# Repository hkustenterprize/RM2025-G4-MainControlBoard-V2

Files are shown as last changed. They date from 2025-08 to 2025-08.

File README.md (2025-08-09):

<div align='center'>
    <h1>RM2025 G4主控板V2</h1>
</div>

<div align='center'>
    <h2>RM2024香港科技大学ENTERPRIZE</h2>
</div>



**开源论坛链接：**

**欢迎加入开源交流QQ群：581184202**

## 文件内容

核心板：[点击在线预览](https://kicanvas.org/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)

扩展板：[点击在线预览](https://kicanvas.org/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)

~~~
RM2025-G4-MainControlBoard-V2
├── image
├── RM2025_G473_MCB             > 核心板工程文件
├── RM2024_G473_MCB_StdExtend   > 标准扩展板工程文件
├── LICENSE
└── README.md
~~~

开源工程文件设计软件为 **KiCAD 8.0**，可以导入立创EDA

每个工程文件文件夹中的内容:

~~~
xxx
├── ibom             > 焊接工具，由 "Interactive HTML BOM" 插件生成
├── production      > 生产文件，由 "Fabrication Toolkit" 插件生成，将其中的zip文件拖入JLC下单助手即可
├── xxx.kicad_pcb   > PCB
├── xxx.kicad_pro   > 主工程，通过双击这个启动KiCAD
└── xxx.kicad_sch   > 原理图
~~~

## 重要参数

主控板分为核心板（下板）和扩展板（上板），两板之间使用80pin BTB接口连接，尺寸上保持为与C板一致的 60x40mm；核心板包含所有核心芯片，扩展板用于引出接口或进行其他功能的扩展。

- MCU: STM32G473VET6
- IMU: ICM-42688P
- TTL: CH343P *2 
- FDCAN *3
- RS485 (硬件流控) *1
- FLASH: W25N01GVZEIG

## 主要变动

较比上代开源（[RM2024 G4主控板开源](https://github.com/hkustenterprize/RM2024-MainControlBoard)），2025赛季的G4主控板根据需求做出了一些变动和优化，主要变化如下：

- 核心板重新 layout，将 QSPI FLASH 的走线进行了等长
- 移除磁力计，移除 CH343P 的流控引脚连接
- 在核心板上增加两个 GPIO 接口
- 将核心板的 MCU 供电由 Buck 改为 LDO
- 扩展板重新 layout，增加了专用于舵轮分电板的 7pin 接口
- 扩展板增加四个 WS2812 LED用于指示状态，将蜂鸣器移至核心板上

## 电源网络

## 外设引脚分配

| <u>CAN</u> (SIT1042T/3) | CAN_TX | CAN_RX |
| ---- | ---- | ---- |
| **CAN1** | PD1 | PD0 |
| **CAN2** | PB6 | PB5  |
| **CAN3** | PB4 | PB3 |

| <u>RS485</u> (SN75176AD) | TX <sup>1</sup> | RX <sup>1</sup> | DE <sup>2</sup>|
| ---- | ---- | ---- |---- |
| **RS485 (UART4)** | PC10 | PC11  | PA15 |

1. 不使用RS485功能时 UART4 可作为 独立UART 使用。
2. 不使用RS485功能时 **DE引脚** 需要配置为 **高电平**，需要确保 **RS485接口** 没有连接。

| <u>TTL</u> (CH343P) | TX | RX |
| ---- | ---- | ---- |
| **TTL1 (UART2A)** | PA2  | PA3  |
| **TTL2 (UART3A)** | PD8  | PD9  |

- 两个TTL芯片均连有状态指示灯，在接口两侧。
- CH343P 接入USB线 (VBUS有供电) 后自动使能。

| <u>IMU</u> (ICM-42688P) | SCLK | MISO | MOSI | CS | DRDY |
| ---- | ---- | ---- | ---- | ---- | ---- |
| **IMU (SPI2)** | PB13  | PB14  | PB15 | PB12 | PB10 |

- **IMU加热**开关由 **PA4** 引脚控制，可以使用 **TIM3_CH2** 或 **GPIO SET/RESET**。
- IMU朝向已在板背面标明

| <u>DR16/i10B</u> | RX <sup>1 2</sup> |
| ---- | ---- |
| **RX1 (UART1C)** | PA10 |
| **RX2 (UART3C)** | PB11 |

1. 两个引脚硬件上连接在一起，可使用任意一个引脚 (对应的串口) 读取接受机数据。
2. 使用一个引脚时，**另外一个引脚一定要悬空**。

| <u>FLASH</u> (W25N01GVZEIG) | CS | CLK | IO0 | IO1 | IO2 | IO3 |
| ---- | ---- | ---- | ---- | ---- | ---- | ---- |
| **FLASH (QSPI1)** | PE11  | PE10  | PB1 | PE13 | PE14 | PA6 |

| <u>其他外设</u>  | Pin |
| ---- | ---- |
| **VIN 24V ADC** | PA8  |
| **5V ADC** | PA9  |
| **Buzzer** | PE3  |
| **LED** | PC13  |
| **Button** | PC15  |

## 串口分配

| | TX | RX | DE | 功能 |
| ---- | ---- | ---- | ---- | ---- |
| **UART1A** | PC4  | PC5  |- | 裁判系统/图传 |
| **UART1B** | PE0  | PE1  |- | 通用串口  |
| **UART1C** | -  | PA10  |-  | 接收机  |
| **UART2A** | PA2  | PA3  |-  | MiniPC1 TTL |
| **UART2B** | PD5  | PD6  |-  | 通用串口  |
| **UART3A** | PD8  | PD9  |-  | MiniPC2 TTL |
| **UART3B** | PB9  | PE15  |-  | 通用串口  |
| **UART3C** | -  | PB11  |-  | 接收机  |
| **UART4** | PC10  | PC11  | PA15 | RS485/通用串口<sup>1</sup>  |
| **UART5** | PC12  | PD2  |-  | 裁判系统/图传  |

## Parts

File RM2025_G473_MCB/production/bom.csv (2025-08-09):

Designator | Footprint | Quantity | Value | LCSC Part #
BZ1 | MLT-9032 | 1 | Buzzer
C1, C13, C17, C18, C36, C39, C41, C44, C76, C78 | 0603 | 10 | 10u
C10, C11, C12, C14, C15, C16, C2, C21, C4, C48, C5, C52, C54, C55, C56, C57, C58, C59, C6, C7, C70, C8, C9 | 0603 | 23 | 100n
C19, C27 | 0603 | 2 | 1u
C22, C23, C60, C61 | 0603 | 4 | 20p
C24, C25, C26, C29, C30 | 1206 | 5 | 10u
C28, C31 | 1206 | 2 | 100u
C3, C38, C43 | 0603 | 3 | 10n
C46, C47 | 0603 | 2 | 0u1
D1, D2, D3 | SOT-23 | 3 | ESD1CAN
D10, D11 | 0603 | 2 | LED
D12, D5 | D_SMF | 2 | SMF5.0A
D14, D6, D7, D9 | D_SMF | 4 | K34
D22 | 0603 | 1 | Yellow
D23 | 0603 | 1 | Green
D4 | D_SMA | 1 | SMAJ24A
D8 | SOT-23 | 1 | SM712
F1 | 1206 | 1 | Fuse
J1 | BTB_P0.8mm_2x40pin_F | 1 | BTB
J10, J11 | JST_GH_SM03B-GHS-TB_1x03-1MP_P1.25mm_Horizontal | 2 | GPIO1
J2 | JST_GH_SM02B-GHS-TB_1x02-1MP_P1.25mm_Horizontal | 1 | RS-485
J20 | AMASS_XT30U-M_1x02_P5.0mm_Vertical | 1 | PWRIn
J22 | PinHeader_1x03_P2.54mm_Vertical | 1 | D-Bus
J28 | Molex_PicoBlade_53261-0471_1x04-1MP_P1.25mm_Horizontal | 1 | SWD
J3 | JST_GH_SM02B-GHS-TB_1x02-1MP_P1.25mm_Horizontal | 1 | CAN1
J4 | JST_GH_SM02B-GHS-TB_1x02-1MP_P1.25mm_Horizontal | 1 | CAN2
J5 | JST_GH_SM02B-GHS-TB_1x02-1MP_P1.25mm_Horizontal | 1 | CAN3
J6 | JST_GH_SM03B-GHS-TB_1x03-1MP_P1.25mm_Horizontal | 1 | UART1A
J7 | JST_GH_SM03B-GHS-TB_1x03-1MP_P1.25mm_Horizontal | 1 | UART5
J8, J9 | JST_PH_B4B-PH-K_1x04_P2.00mm_Vertical | 2 | USB
L1 | L_Sunlord_MWSA0402S | 1 | 6u8
Q1, Q4 | SOT-23 | 2 | AO3400A
R1, R10, R12, R16, R17, R52 | 0603 | 6 | 1k
R11 | 0603 | 1 | 33k
R13, R18, R24, R25, R26, R54, R59, R61, R9 | 0603 | 9 | 10k
R14, R2, R3, R4, R6 | 0603 | 5 | 120R
R15, R51 | 0603 | 2 | 2k2
R19, R20, R21, R57, R8 | 0603 | 5 | 33R
R23 | 0603 | 1 | 54k6
R5, R7 | 0603 | 2 | 4k7
R62 | 1206 | 1 | (36R)
RN1, RN12, RN13, RN19, RN2, RN21, RN4, RN5 | R_Array_Concave_4x0603 | 8 | 82R
SW1 | Button_Side | 1 | NRST
SW2 | Button_Side | 1 | BOOT0
SW4 | Button_Side | 1 | BTN
U1 | LQFP-100_14x14mm_P0.5mm | 1 | STM32G473VETx
U10, U11, U3 | SOT-23-5 | 3 | RS3236
U12, U4, U7 | SOIC-8_3.9x4.9mm_P1.27mm | 3 | TJA1042T-3
U13 | SOIC-8_3.9x4.9mm_P1.27mm | 1 | SN75176AD
U14, U15, U5, U6 | USON-10_2.5x1.0mm_P0.5mm_Mod | 4 | TPD4E02B04DQA
U16, U17 | TQFN-16-1EP_3x3mm_P0.5mm_EP1.6x1.6mm | 2 | CH343P
U2 | PQFN50P300X250X97-14N | 1 | ICM-42688-P
U8 | SOT-23-6 | 1 | RY8411
U9 | WSON-8_FLASH | 1 | W25N01GVZEIG
Y1 | Crystal_SMD_3225-4Pin_3.2x2.5mm | 1 | 3225 25MHz

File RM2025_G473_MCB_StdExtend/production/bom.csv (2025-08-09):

Designator | Footprint | Quantity | Value | LCSC Part #
C1, C2, C3, C4, C5, C6, C78 | 0603 | 7 | 4u7
C7 | 0603 | 1 | 100n
D1, D3, D5 | WS2812B-2020 | 3 | WS2812B-2020
D2 | WS2812B-2020 | 1 | RM25:WS2812B-2020
D4 | D_SMF | 1 | SMFJ5V0A
D6 | D_SMF | 1 | D_Schottky
F1 | 1206 | 1 | 1A
J1, J14 | JST_GH_BM02B-GHS-TBT_1x02-1MP_P1.25mm_Vertical | 2 | RS-485
J10, J11, J2, J3 | JST_GH_BM03B-GHS-TBT_1x03-1MP_P1.25mm_Vertical | 4 | GPIO
J12 | BTB_P0.8mm_2x40pin_M | 1 | BTB
J13, J15, J16, J17, J8, J9 | JST_GH_BM02B-GHS-TBT_1x02-1MP_P1.25mm_Vertical | 6 | CAN
J18, J21, J23, J24, J25 | JST_GH_BM07B-GHS-TBT_1x07-1MP_P1.25mm_Vertical | 5 | Conn_01x07_MountingPin
J19 | Molex_PicoBlade_53261-0271_1x02-1MP_P1.25mm_Horizontal | 1 | LASER
J28 | Molex_PicoBlade_53261-0471_1x04-1MP_P1.25mm_Horizontal | 1 | SWD
J6 | JST_GH_BM03B-GHS-TBT_1x03-1MP_P1.25mm_Vertical | 1 | UART1A
J7 | JST_GH_BM03B-GHS-TBT_1x03-1MP_P1.25mm_Vertical | 1 | UART5
Q1 | SOT-23 | 1 | AO3400A
R1, R2, R3, R5 | 0603 | 4 | 120R
R4 | 0603 | 1 | 10k
RN1, RN2 | R_Array_Concave_4x0603 | 2 | 82R
SW1 | Button_PTS810 | 1 | BTN
SW2 | Button_PTS810 | 1 | NRST
U1, U15 | USON-10_2.5x1.0mm_P0.5mm_Mod | 2 | TPD4E02B04DQA

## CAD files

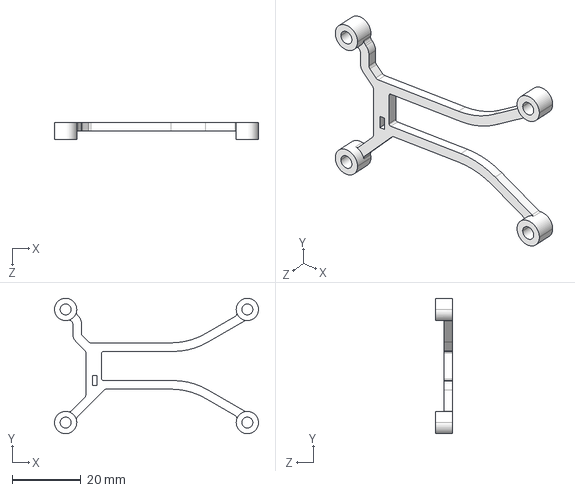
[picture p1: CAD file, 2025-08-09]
3DP垫片_一定要加.STEP
59.5 x 39.5 x 5.00 mm

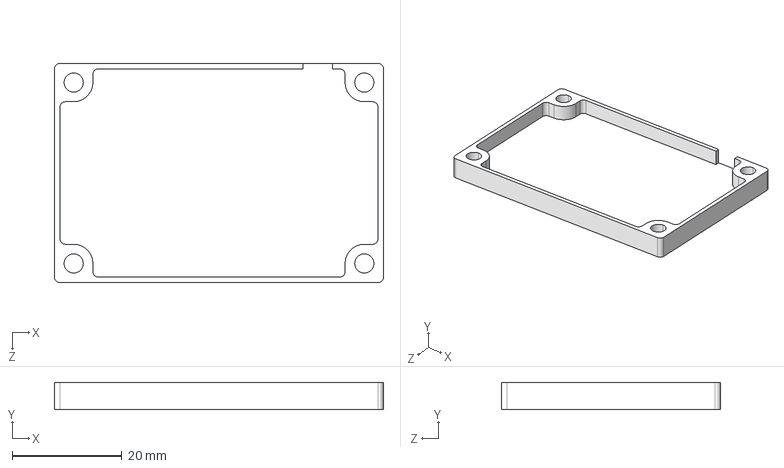
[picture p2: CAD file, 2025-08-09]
3DP底座.STEP
60.0 x 5.00 x 40.0 mm

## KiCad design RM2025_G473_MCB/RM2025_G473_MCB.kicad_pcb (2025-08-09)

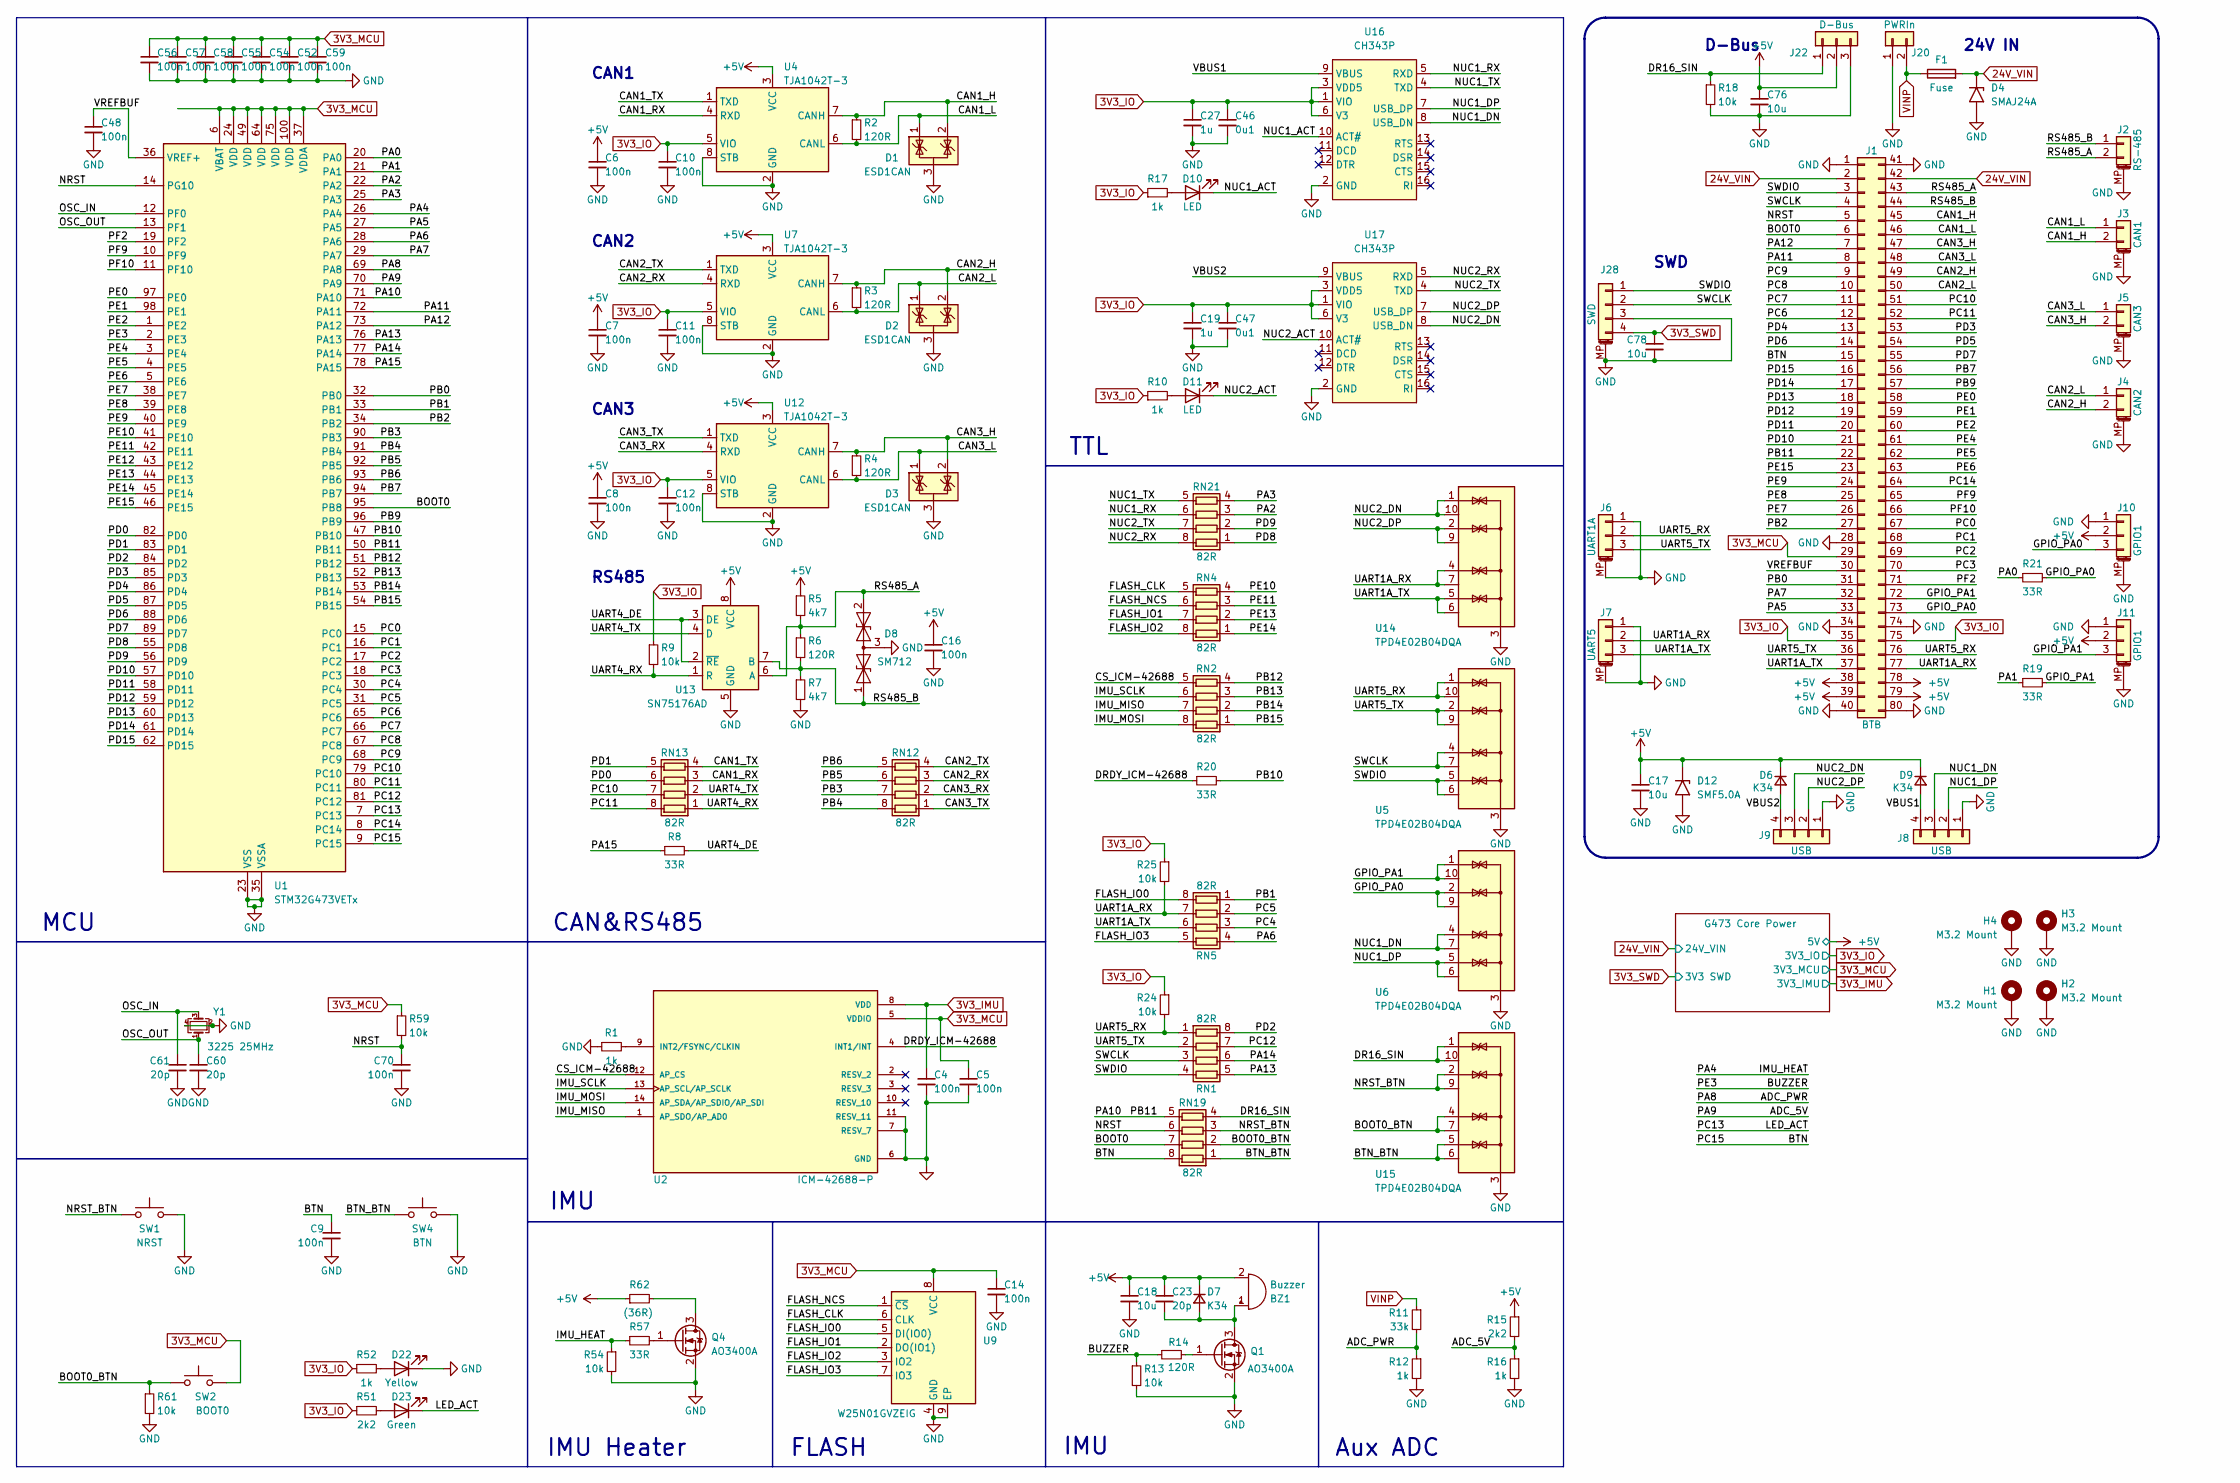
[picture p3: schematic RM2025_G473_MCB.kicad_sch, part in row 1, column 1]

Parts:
BZ1: Buzzer; MLT-9032
C4, C5, C6, C7, C8, C9, C10, C11, C12, C14, C16, C48, C52, C54, C55, C56, C57, C58, C59, C70: 100n; C_0603_1608Metric
C17, C18, C76, C78: 10u; C_0603_1608Metric
C19, C27: 1u; C_0603_1608Metric
C23, C60, C61: 20p; C_0603_1608Metric
C46, C47: 0u1; C_0603_1608Metric
D1, D2, D3: ESD1CAN; SOT-23
D4: SMAJ24A; D_SMA
D6, D7, D9: K34; D_SMF
D8: SM712; SOT-23
D10, D11: LED; LED_0603_1608Metric
D12: SMF5.0A; D_SMF
D22: Yellow; LED_0603_1608Metric
D23: Green; LED_0603_1608Metric
F1: Fuse; Fuse_1206_3216Metric
H1, H2, H3, H4: M3.2 Mount; MountingHole_3.2mm_M3_DIN965_Pad
J1: BTB; BTB_P0.8mm_2x40pin_F
J2: RS-485; JST_GH_SM02B-GHS-TB_1x02-1MP_P1.25mm_Horizontal
J3: CAN1; JST_GH_SM02B-GHS-TB_1x02-1MP_P1.25mm_Horizontal
J4: CAN2; JST_GH_SM02B-GHS-TB_1x02-1MP_P1.25mm_Horizontal
J5: CAN3; JST_GH_SM02B-GHS-TB_1x02-1MP_P1.25mm_Horizontal
J6: UART1A; JST_GH_SM03B-GHS-TB_1x03-1MP_P1.25mm_Horizontal
J7: UART5; JST_GH_SM03B-GHS-TB_1x03-1MP_P1.25mm_Horizontal
J8, J9: USB; JST_PH_B4B-PH-K_1x04_P2.00mm_Vertical
J10, J11: GPIO1; JST_GH_SM03B-GHS-TB_1x03-1MP_P1.25mm_Horizontal
J20: PWRIn; AMASS_XT30U-M_1x02_P5.0mm_Vertical
J22: D-Bus; PinHeader_1x03_P2.54mm_Vertical
J28: SWD; Molex_PicoBlade_53261-0471_1x04-1MP_P1.25mm_Horizontal
Q1, Q4: AO3400A; SOT-23
R1, R10, R12, R16, R17, R52: 1k; R_0603_1608Metric
R2, R3, R4, R6, R14: 120R; R_0603_1608Metric
R5, R7: 4k7; R_0603_1608Metric
R8, R19, R20, R21, R57: 33R; R_0603_1608Metric
R9, R13, R18, R24, R25, R54, R59, R61: 10k; R_0603_1608Metric
R11: 33k; R_0603_1608Metric
R15, R51: 2k2; R_0603_1608Metric
R62: (36R); R_1206_3216Metric
RN1, RN2, RN4, RN5, RN12, RN13, RN19, RN21: 82R; R_Array_Concave_4x0603
SW1: NRST; Button_Side
SW2: BOOT0; Button_Side
SW4: BTN; Button_Side
U1: STM32G473VETx; LQFP-100_14x14mm_P0.5mm
U2: ICM-42688-P; PQFN50P300X250X97-14N; PARTREV 1.2
U4, U7, U12: TJA1042T-3; SOIC-8_3.9x4.9mm_P1.27mm
U5, U6, U14, U15: TPD4E02B04DQA; USON-10_2.5x1.0mm_P0.5mm_Mod
U9: W25N01GVZEIG; WSON-8_FLASH
U13: SN75176AD; SOIC-8_3.9x4.9mm_P1.27mm
U16, U17: CH343P; TQFN-16-1EP_3x3mm_P0.5mm_EP1.6x1.6mm
Y1: 3225 25MHz; Crystal_SMD_3225-4Pin_3.2x2.5mm

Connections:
3V3_IMU: C4.1, U2.8 (VDD); also elsewhere on the board
3V3_IO: C10.1, C11.1, C12.1, C19.1, C27.1, C46.1, C47.1, J1.35, J1.75, R9.1, R10.1, R17.1, R24.1, R25.1, R51.1, R52.1, U4.5 (VIO), U7.5 (VIO), U12.5 (VIO), U16.1 (VIO), U16.3 (VDD5), U16.6 (V3), U17.1 (VIO), U17.3 (VDD5), U17.6 (V3); also elsewhere on the board
3V3_MCU: C5.1, C14.1, C52.1, C54.1, C55.1, C56.1, C57.1, C58.1, C59.1, J1.29, R59.1, SW2.2, U1.6 (VBAT), U1.24 (VDD), U1.37 (VDDA), U1.49 (VDD), U1.64 (VDD), U1.75 (VDD), U1.100 (VDD), U2.5 (VDDIO), U9.8 (VCC); also elsewhere on the board
3V3_SWD: C78.1, J28.4; also elsewhere on the board
24V_VIN: D4.1 (A1), F1.2, J1.2, J1.42; also elsewhere on the board
+5V: BZ1.2 (+), C6.1, C7.1, C8.1, C16.1, C17.1, C18.1, C23.1, C76.1, D6.1 (K), D7.1 (K), D9.1 (K), D12.1 (A1), J1.38, J1.39, J1.78, J1.79, J10.2, J11.2, J22.2, R5.1, R15.1, R62.1, U4.3 (VCC), U7.3 (VCC), U12.3 (VCC), U13.8 (VCC); also elsewhere on the board
/ADC_5V: R15.2, R16.1, U1.70 (PA9)
/ADC_PWR: R11.2, R12.1, U1.69 (PA8)
/BOOT0: J1.6, RN19.7 (R2.2), U1.95 (PB8)
/BOOT0_BTN: R61.1, RN19.2 (R2.1), SW2.1, U15.4 (IO3), U15.7 (NC)
/BTN: C9.1, J1.15, RN19.8 (R1.2), U1.9 (PC15)
/BTN_BTN: RN19.1 (R1.1), SW4.1, U15.5 (IO4), U15.6 (NC)
/BUZZER: R13.1, R14.1, U1.2 (PE3)
/CAN1_H: D1.2 (K), J1.45, J3.2, R2.1, U4.7 (CANH)
/CAN1_L: D1.1 (K), J1.46, J3.1, R2.2, U4.6 (CANL)
/CAN1_RX: RN13.3 (R3.1), U4.4 (RXD)
/CAN1_TX: RN13.4 (R4.1), U4.1 (TXD)
/CAN2_H: D2.2 (K), J1.49, J4.2, R3.1, U7.7 (CANH)
/CAN2_L: D2.1 (K), J1.50, J4.1, R3.2, U7.6 (CANL)
/CAN2_RX: RN12.3 (R3.1), U7.4 (RXD)
/CAN2_TX: RN12.4 (R4.1), U7.1 (TXD)
/CAN3_H: D3.2 (K), J1.47, J5.2, R4.1, U12.7 (CANH)
/CAN3_L: D3.1 (K), J1.48, J5.1, R4.2, U12.6 (CANL)
/CAN3_RX: RN12.2 (R2.1), U12.4 (RXD)
/CAN3_TX: RN12.1 (R1.1), U12.1 (TXD)
/CS_ICM-42688: RN2.5 (R4.2), U2.12 (AP_CS)
/DR16_SIN: J22.1, R18.1, RN19.4 (R4.1), U15.1 (IO1), U15.10 (NC)
/DRDY_ICM-42688: R20.1, U2.4 (INT1/INT)
/FLASH_CLK: RN4.5 (R4.2), U9.6 (CLK)
/FLASH_IO0: RN5.8 (R1.2), U9.5 (DI(IO0))
/FLASH_IO1: RN4.7 (R2.2), U9.2 (DO(IO1))
/FLASH_IO2: RN4.8 (R1.2), U9.3 (IO2)
/FLASH_IO3: RN5.5 (R4.2), U9.7 (IO3)
/FLASH_NCS: RN4.6 (R3.2), U9.1 (~CS)
/GPIO_PA0: J1.73, J10.3, R21.2, U6.2 (IO2), U6.9 (NC)
/GPIO_PA1: J1.72, J11.3, R19.2, U6.1 (IO1), U6.10 (NC)
/IMU_HEAT: R54.1, R57.1, U1.26 (PA4)
/IMU_MISO: RN2.7 (R2.2), U2.1 (AP_SDO/AP_AD0)
/IMU_MOSI: RN2.8 (R1.2), U2.14 (AP_SDA/AP_SDIO/AP_SDI)
/IMU_SCLK: RN2.6 (R3.2), U2.13 (AP_SCL/AP_SCLK)
/LED_ACT: D23.1 (K), U1.7 (PC13)
/NRST: C70.1, J1.5, R59.2, RN19.6 (R3.2), U1.14 (PG10)
/NRST_BTN: RN19.3 (R3.1), SW1.1, U15.2 (IO2), U15.9 (NC)
/NUC1_ACT: D10.1 (K), U16.10 (ACT#)
/NUC1_DN: J8.3, U6.4 (IO3), U6.7 (NC), U16.8 (USB_DN)
/NUC1_DP: J8.2, U6.5 (IO4), U6.6 (NC), U16.7 (USB_DP)
/NUC1_RX: RN21.6 (R3.2), U16.5 (RXD)
/NUC1_TX: RN21.5 (R4.2), U16.4 (TXD)
/NUC2_ACT: D11.1 (K), U17.10 (ACT#)
/NUC2_DN: J9.3, U14.1 (IO1), U14.10 (NC), U17.8 (USB_DN)
/NUC2_DP: J9.2, U14.2 (IO2), U14.9 (NC), U17.7 (USB_DP)
/NUC2_RX: RN21.8 (R1.2), U17.5 (RXD)
/NUC2_TX: RN21.7 (R2.2), U17.4 (TXD)
/OSC_IN: C61.1, U1.12 (PF0), Y1.3
/OSC_OUT: C60.1, U1.13 (PF1), Y1.1
/PA0: R21.1, U1.20 (PA0)
/PA1: R19.1, U1.21 (PA1)
/PA2: RN21.3 (R3.1), U1.22 (PA2)
/PA3: RN21.4 (R4.1), U1.25 (PA3)
/PA5: J1.33, U1.27 (PA5)
/PA6: RN5.4 (R4.1), U1.28 (PA6)
/PA7: J1.32, U1.29 (PA7)
/PA10: J1.22, RN19.5 (R4.2), U1.50 (PB11), U1.71 (PA10)
/PA11: J1.8, U1.72 (PA11)
/PA12: J1.7, U1.73 (PA12)
/PA13: RN1.5 (R4.2), U1.76 (PA13)
/PA14: RN1.6 (R3.2), U1.77 (PA14)
/PA15: R8.1, U1.78 (PA15)
/PB0: J1.31, U1.32 (PB0)
/PB1: RN5.1 (R1.1), U1.33 (PB1)
/PB2: J1.27, U1.34 (PB2)
/PB3: RN12.7 (R2.2), U1.90 (PB3)
/PB4: RN12.8 (R1.2), U1.91 (PB4)
/PB5: RN12.6 (R3.2), U1.92 (PB5)
/PB6: RN12.5 (R4.2), U1.93 (PB6)
/PB7: J1.56, U1.94 (PB7)
/PB9: J1.57, U1.96 (PB9)
/PB10: R20.2, U1.47 (PB10)
/PB12: RN2.4 (R4.1), U1.51 (PB12)
/PB13: RN2.3 (R3.1), U1.52 (PB13)
/PB14: RN2.2 (R2.1), U1.53 (PB14)
/PB15: RN2.1 (R1.1), U1.54 (PB15)
/PC0: J1.67, U1.15 (PC0)
/PC1: J1.68, U1.16 (PC1)
/PC2: J1.69, U1.17 (PC2)
/PC3: J1.70, U1.18 (PC3)
/PC4: RN5.3 (R3.1), U1.30 (PC4)
/PC5: RN5.2 (R2.1), U1.31 (PC5)
/PC6: J1.12, U1.65 (PC6)
/PC7: J1.11, U1.66 (PC7)
/PC8: J1.10, U1.67 (PC8)
/PC9: J1.9, U1.68 (PC9)
/PC10: J1.51, RN13.7 (R2.2), U1.79 (PC10)
/PC11: J1.52, RN13.8 (R1.2), U1.80 (PC11)
/PC12: RN1.7 (R2.2), U1.81 (PC12)
/PC14: J1.64, U1.8 (PC14)
/PD0: RN13.6 (R3.2), U1.82 (PD0)
/PD1: RN13.5 (R4.2), U1.83 (PD1)
/PD2: RN1.8 (R1.2), U1.84 (PD2)
/PD3: J1.53, U1.85 (PD3)
/PD4: J1.13, U1.86 (PD4)
/PD5: J1.54, U1.87 (PD5)
/PD6: J1.14, U1.88 (PD6)
/PD7: J1.55, U1.89 (PD7)
/PD8: RN21.1 (R1.1), U1.55 (PD8)
/PD9: RN21.2 (R2.1), U1.56 (PD9)
/PD10: J1.21, U1.57 (PD10)
/PD11: J1.20, U1.58 (PD11)
/PD12: J1.19, U1.59 (PD12)
/PD13: J1.18, U1.60 (PD13)
/PD14: J1.17, U1.61 (PD14)
/PD15: J1.16, U1.62 (PD15)
/PE0: J1.58, U1.97 (PE0)
/PE1: J1.59, U1.98 (PE1)
/PE2: J1.60, U1.1 (PE2)
/PE4: J1.61, U1.3 (PE4)
/PE5: J1.62, U1.4 (PE5)
/PE6: J1.63, U1.5 (PE6)
/PE7: J1.26, U1.38 (PE7)
/PE8: J1.25, U1.39 (PE8)
/PE9: J1.24, U1.40 (PE9)
/PE10: RN4.4 (R4.1), U1.41 (PE10)
/PE11: RN4.3 (R3.1), U1.42 (PE11)
/PE12: U1.43 (PE12)
/PE13: RN4.2 (R2.1), U1.44 (PE13)
/PE14: RN4.1 (R1.1), U1.45 (PE14)
/PE15: J1.23, U1.46 (PE15)
/PF2: J1.71, U1.19 (PF2)
/PF9: J1.65, U1.10 (PF9)
/PF10: J1.66, U1.11 (PF10)
/RS485_A: D8.2 (A2), J1.43, J2.2, R5.2, R6.1, U13.6 (A)
/RS485_B: D8.1 (A1), J1.44, J2.1, R6.2, R7.1, U13.7 (B)
/SWCLK: J1.4, J28.2, RN1.3 (R3.1), U5.4 (IO3), U5.7 (NC)
/SWDIO: J1.3, J28.1, RN1.4 (R4.1), U5.5 (IO4), U5.6 (NC)
/UART1A_RX: J1.77, J7.2, R25.2, RN5.7 (R2.2), U14.4 (IO3), U14.7 (NC)
/UART1A_TX: J1.37, J7.3, RN5.6 (R3.2), U14.5 (IO4), U14.6 (NC)
/UART4_DE: R8.2, U13.2 (~RE), U13.3 (DE)
/UART4_RX: R9.2, RN13.1 (R1.1), U13.1 (R)
/UART4_TX: RN13.2 (R2.1), U13.4 (D)
/UART5_RX: J1.76, J6.2, R24.2, RN1.1 (R1.1), U5.1 (IO1), U5.10 (NC)
/UART5_TX: J1.36, J6.3, RN1.2 (R2.1), U5.2 (IO2), U5.9 (NC)
/VBUS1: D9.2 (A), J8.4, U16.9 (VBUS)
/VBUS2: D6.2 (A), J9.4, U17.9 (VBUS)
/VREFBUF: C48.1, J1.30, U1.36 (VREF+)
GND: C4.2, C5.2, C6.2, C7.2, C8.2, C9.2, C10.2, C11.2, C12.2, C14.2, C16.2, C17.2, C18.2, C19.2, C27.2, C46.2, C47.2, C48.2, C52.2, C54.2, C55.2, C56.2, C57.2, C58.2, C59.2, C60.2, C61.2, C70.2, C76.2, C78.2, D1.3 (A), D2.3 (A), D3.3 (A), D4.2 (A2), D8.3 (common), D12.2 (A2), D22.1 (K), H1.1, H2.1, H3.1, H4.1, J1.1, J1.28, J1.34, J1.40, J1.41, J1.74, J1.80, J2.MP (MountPin), J3.MP (MountPin), J4.MP (MountPin), J5.MP (MountPin), J6.1, J6.MP (MountPin), J7.1, J7.MP (MountPin), J8.1, J9.1, J10.1, J10.MP (MountPin), J11.1, J11.MP (MountPin), J20.1, J22.3, J28.3, J28.MP (MountPin), Q1.2 (S), Q4.2 (S), R1.1, R7.2, R12.2, R13.2, R16.2, R18.2, R54.2, R61.2, SW1.2, SW4.2, U1.23 (VSS), U1.35 (VSSA), U1.48 (VSS), U1.63 (VSS), U1.74 (VSS), U1.99 (VSS), U2.6 (GND), U2.7 (RESV_7), U2.11 (RESV_11), U4.2 (GND), U4.8 (STB), U5.3 (G), U5.8 (G), U6.3 (G), U6.8 (G), U7.2 (GND), U7.8 (STB), U9.4 (GND), U9.9 (EP), U12.2 (GND), U12.8 (STB), U13.5 (GND), U14.3 (G), U14.8 (G), U15.3 (G), U15.8 (G), U16.2 (GND), U16.17 (GND), U17.2 (GND), U17.17 (GND), Y1.2, Y1.4; also elsewhere on the board
unnamed: BZ1.1 (-), C23.2, D7.2 (A), Q1.3 (D)
unnamed: D10.2 (A), R17.2
unnamed: D11.2 (A), R10.2
unnamed: D22.2 (A), R52.2
unnamed: D23.2 (A), R51.2
unnamed: Q1.1 (G), R14.2
unnamed: Q4.3 (D), R62.2
unnamed: Q4.1 (G), R57.2
unnamed: R1.2, U2.9 (INT2/FSYNC/CLKIN)
VINP: F1.1, J20.2, R11.1

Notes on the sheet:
CAN1
24V IN
CAN&RS485
IMU
CAN3
RS485
FLASH
SWD
TTL
Aux ADC
MCU
IMU Heater
D-Bus
CAN2

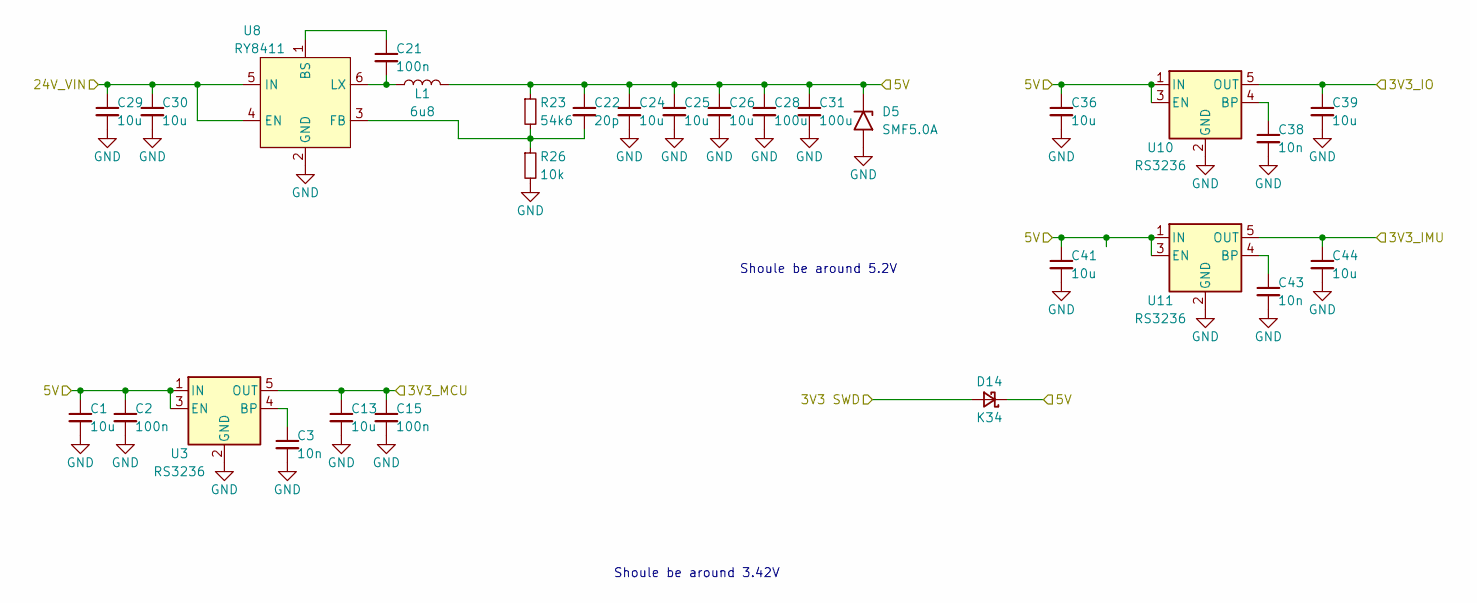
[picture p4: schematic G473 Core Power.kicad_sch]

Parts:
C1, C13, C36, C39, C41, C44: 10u; C_0603_1608Metric
C2, C15, C21: 100n; C_0603_1608Metric
C3, C38, C43: 10n; C_0603_1608Metric
C22: 20p; C_0603_1608Metric
C24, C25, C26, C29, C30: 10u; C_1206_3216Metric
C28, C31: 100u; C_1206_3216Metric
D5: SMF5.0A; D_SMF
D14: K34; D_SMF
L1: 6u8; L_Sunlord_MWSA0402S
R23: 54k6; R_0603_1608Metric
R26: 10k; R_0603_1608Metric
U3, U10, U11: RS3236; SOT-23-5
U8: RY8411; SOT-23-6

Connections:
3V3_IMU: C44.1, U11.5 (OUT); also elsewhere on the board
3V3_IO: C39.1, U10.5 (OUT); also elsewhere on the board
3V3_MCU: C13.1, C15.1, U3.5 (OUT); also elsewhere on the board
3V3_SWD: D14.2 (A); also elsewhere on the board
24V_VIN: C29.1, C30.1, U8.4 (EN), U8.5 (IN); also elsewhere on the board
+5V: C1.1, C2.1, C22.1, C24.1, C25.1, C26.1, C28.1, C31.1, C36.1, C41.1, D5.1 (A1), D14.1 (K), L1.2, R23.1, U3.1 (IN), U3.3 (EN), U10.1 (IN), U10.3 (EN), U11.1 (IN), U11.3 (EN); also elsewhere on the board
GND: C1.2, C2.2, C3.2, C13.2, C15.2, C24.2, C25.2, C26.2, C28.2, C29.2, C30.2, C31.2, C36.2, C38.2, C39.2, C41.2, C43.2, C44.2, D5.2 (A2), R26.2, U3.2 (GND), U8.2 (GND), U10.2 (GND), U11.2 (GND); also elsewhere on the board
unnamed: C3.1, U3.4 (BP)
unnamed: C21.1, U8.1 (BS)
unnamed: C22.2, R23.2, R26.1, U8.3 (FB)
unnamed: C21.2, L1.1, U8.6 (LX)
unnamed: C38.1, U10.4 (BP)
unnamed: C43.1, U11.4 (BP)

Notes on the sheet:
Shoule be around 5.2V
Shoule be around 3.42V

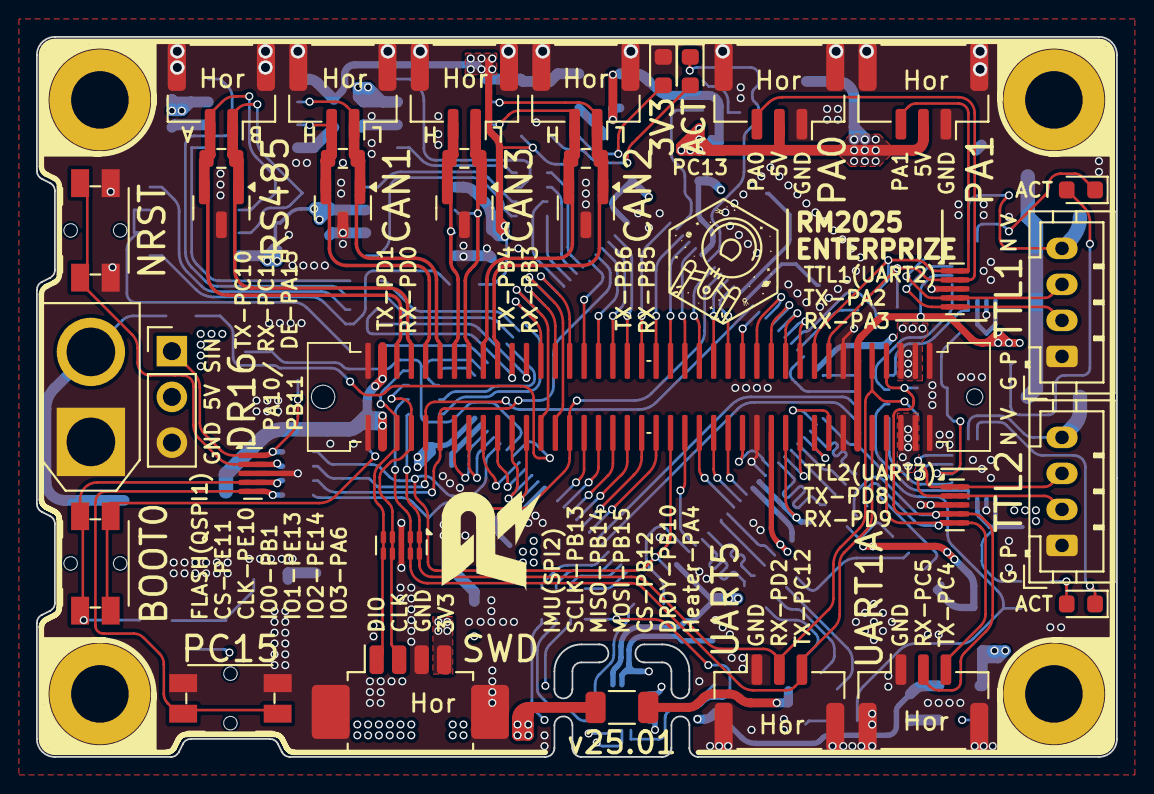
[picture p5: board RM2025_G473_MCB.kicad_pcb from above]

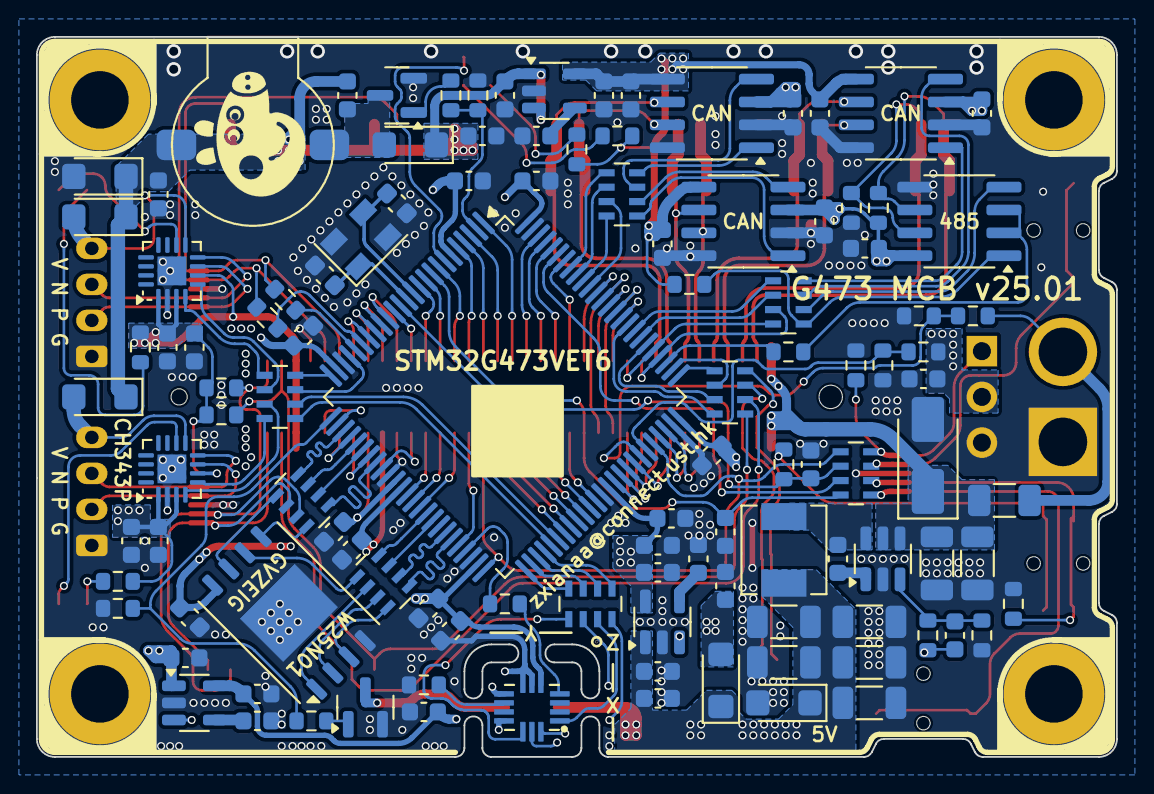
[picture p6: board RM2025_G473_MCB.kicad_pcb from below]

Board: 4 copper layers, 60.0 x 40.0 mm, 150 parts (112 on the bottom side), 160 nets.

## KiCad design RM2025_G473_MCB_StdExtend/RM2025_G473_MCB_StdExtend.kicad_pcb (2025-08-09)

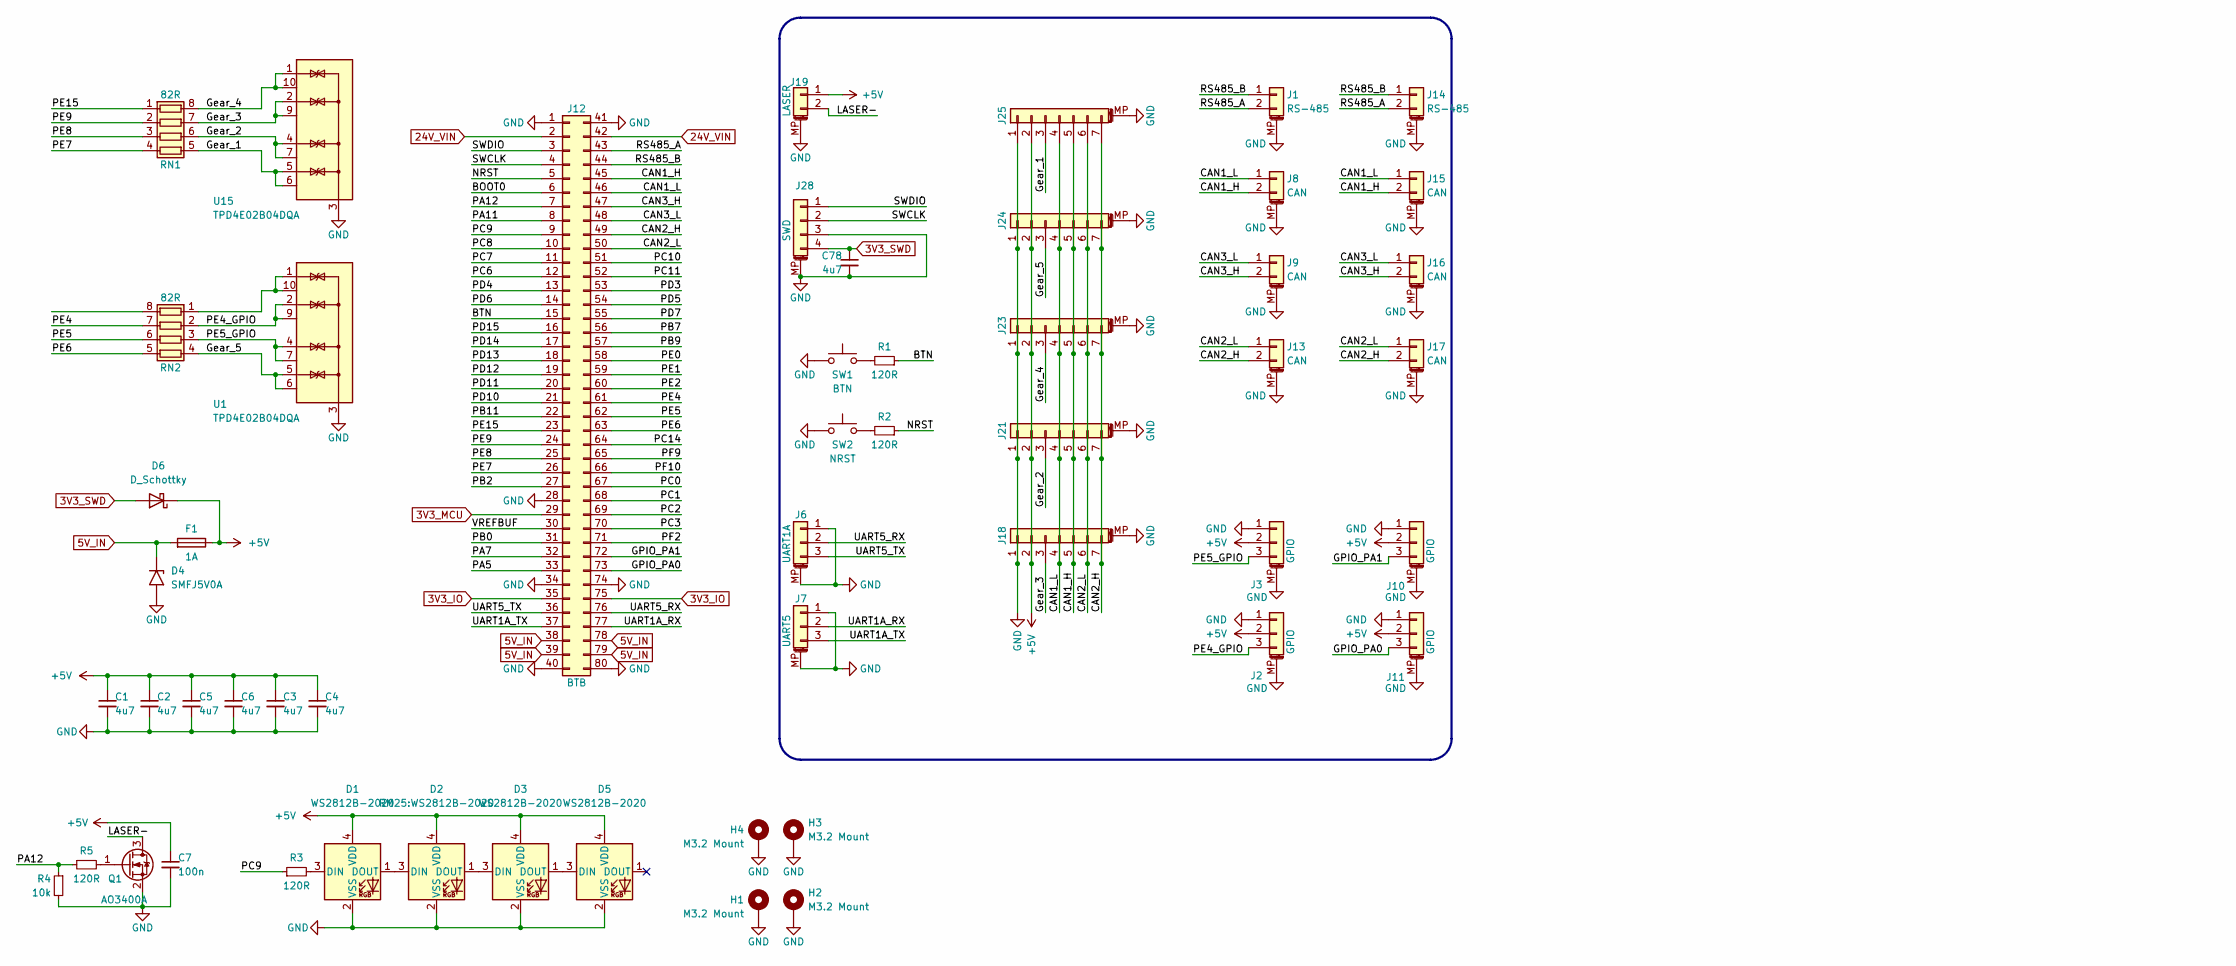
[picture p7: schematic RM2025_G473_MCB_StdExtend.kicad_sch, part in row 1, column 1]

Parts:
C1, C2, C3, C4, C5, C6, C78: 4u7; C_0603_1608Metric
C7: 100n; C_0603_1608Metric
D1, D3, D5: WS2812B-2020
D2: RM25:WS2812B-2020; WS2812B-2020
D4: SMFJ5V0A; D_SMF
D6: D_Schottky; D_SMF
F1: 1A; Fuse_1206_3216Metric
H1, H2, H3, H4: M3.2 Mount; MountingHole_3.2mm_M3_DIN965_Pad
J1, J14: RS-485; JST_GH_BM02B-GHS-TBT_1x02-1MP_P1.25mm_Vertical
J2, J3, J10, J11: GPIO; JST_GH_BM03B-GHS-TBT_1x03-1MP_P1.25mm_Vertical
J6: UART1A; JST_GH_BM03B-GHS-TBT_1x03-1MP_P1.25mm_Vertical
J7: UART5; JST_GH_BM03B-GHS-TBT_1x03-1MP_P1.25mm_Vertical
J8, J9, J13, J15, J16, J17: CAN; JST_GH_BM02B-GHS-TBT_1x02-1MP_P1.25mm_Vertical
J12: BTB; BTB_P0.8mm_2x40pin_M
J18, J21, J23, J24, J25: Conn_01x07_MountingPin; JST_GH_BM07B-GHS-TBT_1x07-1MP_P1.25mm_Vertical
J19: LASER; Molex_PicoBlade_53261-0271_1x02-1MP_P1.25mm_Horizontal
J28: SWD; Molex_PicoBlade_53261-0471_1x04-1MP_P1.25mm_Horizontal
Q1: AO3400A; SOT-23
R1, R2, R3, R5: 120R; R_0603_1608Metric
R4: 10k; R_0603_1608Metric
RN1, RN2: 82R; R_Array_Concave_4x0603
SW1: BTN; Button_PTS810
SW2: NRST; Button_PTS810
U1, U15: TPD4E02B04DQA; USON-10_2.5x1.0mm_P0.5mm_Mod

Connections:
3V3_IO: J12.35, J12.75
3V3_MCU: J12.29
3V3_SWD: C78.1, D6.2 (A), J28.4
5V_IN: D4.1 (A1), F1.2, J12.38, J12.39, J12.78, J12.79
24V_VIN: J12.2, J12.42
+5V: C1.1, C2.1, C3.1, C4.1, C5.1, C6.1, C7.1, D1.4 (VDD), D2.4 (VDD), D3.4 (VDD), D5.4 (VDD), D6.1 (K), F1.1, J2.2, J3.2, J10.2, J11.2, J18.2, J19.1, J21.2, J23.2, J24.2, J25.2
/BOOT0: J12.6
/BTN: J12.15, R1.1
/CAN1_H: J8.2, J12.45, J15.2, J18.5, J21.5, J23.5, J24.5, J25.5
/CAN1_L: J8.1, J12.46, J15.1, J18.4, J21.4, J23.4, J24.4, J25.4
/CAN2_H: J12.49, J13.2, J17.2, J18.7, J21.7, J23.7, J24.7, J25.7
/CAN2_L: J12.50, J13.1, J17.1, J18.6, J21.6, J23.6, J24.6, J25.6
/CAN3_H: J9.2, J12.47, J16.2
/CAN3_L: J9.1, J12.48, J16.1
/GPIO_PA0: J11.3, J12.73
/GPIO_PA1: J10.3, J12.72
/Gear_1: J25.3, RN1.5 (R4.2), U15.5 (IO4), U15.6 (NC)
/Gear_2: J21.3, RN1.6 (R3.2), U15.4 (IO3), U15.7 (NC)
/Gear_3: J18.3, RN1.7 (R2.2), U15.2 (IO2), U15.9 (NC)
/Gear_4: J23.3, RN1.8 (R1.2), U15.1 (IO1), U15.10 (NC)
/Gear_5: J24.3, RN2.4 (R4.1), U1.5 (IO4), U1.6 (NC)
/LASER-: J19.2, Q1.3 (D)
/NRST: J12.5, R2.1
/PA5: J12.33
/PA7: J12.32
/PA11: J12.8
/PA12: J12.7, R4.1, R5.1
/PB0: J12.31
/PB2: J12.27
/PB7: J12.56
/PB9: J12.57
/PB11: J12.22
/PC0: J12.67
/PC1: J12.68
/PC2: J12.69
/PC3: J12.70
/PC6: J12.12
/PC7: J12.11
/PC8: J12.10
/PC9: J12.9, R3.1
/PC10: J12.51
/PC11: J12.52
/PC14: J12.64
/PD3: J12.53
/PD4: J12.13
/PD5: J12.54
/PD6: J12.14
/PD7: J12.55
/PD10: J12.21
/PD11: J12.20
/PD12: J12.19
/PD13: J12.18
/PD14: J12.17
/PD15: J12.16
/PE0: J12.58
/PE1: J12.59
/PE2: J12.60
/PE4: J12.61, RN2.7 (R2.2)
/PE4_GPIO: J2.3, RN2.2 (R2.1), U1.2 (IO2), U1.9 (NC)
/PE5: J12.62, RN2.6 (R3.2)
/PE5_GPIO: J3.3, RN2.3 (R3.1), U1.4 (IO3), U1.7 (NC)
/PE6: J12.63, RN2.5 (R4.2)
/PE7: J12.26, RN1.4 (R4.1)
/PE8: J12.25, RN1.3 (R3.1)
/PE9: J12.24, RN1.2 (R2.1)
/PE15: J12.23, RN1.1 (R1.1)
/PF2: J12.71
/PF9: J12.65
/PF10: J12.66
/RS485_A: J1.2, J12.43, J14.2
/RS485_B: J1.1, J12.44, J14.1
/SWCLK: J12.4, J28.2
/SWDIO: J12.3, J28.1
/UART1A_RX: J7.2, J12.77
/UART1A_TX: J7.3, J12.37
/UART5_RX: J6.2, J12.76
/UART5_TX: J6.3, J12.36
/VREFBUF: J12.30
GND: C1.2, C2.2, C3.2, C4.2, C5.2, C6.2, C7.2, C78.2, D1.2 (VSS), D2.2 (VSS), D3.2 (VSS), D4.2 (A2), D5.2 (VSS), H1.1, H2.1, H3.1, H4.1, J1.MP (MountPin), J2.1, J2.MP (MountPin), J3.1, J3.MP (MountPin), J6.1, J6.MP (MountPin), J7.1, J7.MP (MountPin), J8.MP (MountPin), J9.MP (MountPin), J10.1, J10.MP (MountPin), J11.1, J11.MP (MountPin), J12.1, J12.28, J12.34, J12.40, J12.41, J12.74, J12.80, J13.MP (MountPin), J14.MP (MountPin), J15.MP (MountPin), J16.MP (MountPin), J17.MP (MountPin), J18.1, J18.MP (MountPin), J19.MP (MountPin), J21.1, J21.MP (MountPin), J23.1, J23.MP (MountPin), J24.1, J24.MP (MountPin), J25.1, J25.MP (MountPin), J28.3, J28.MP (MountPin), Q1.2 (S), R4.2, SW1.2, SW2.2, U1.3 (G), U1.8 (G), U15.3 (G), U15.8 (G)
unnamed: D1.3 (DIN), R3.2
unnamed: D1.1 (DOUT), D2.3 (DIN)
unnamed: D2.1 (DOUT), D3.3 (DIN)
unnamed: D3.1 (DOUT), D5.3 (DIN)
unnamed: Q1.1 (G), R5.2
unnamed: R1.2, SW1.1
unnamed: R2.2, SW2.1
unnamed: RN2.1 (R1.1), U1.1 (IO1), U1.10 (NC)

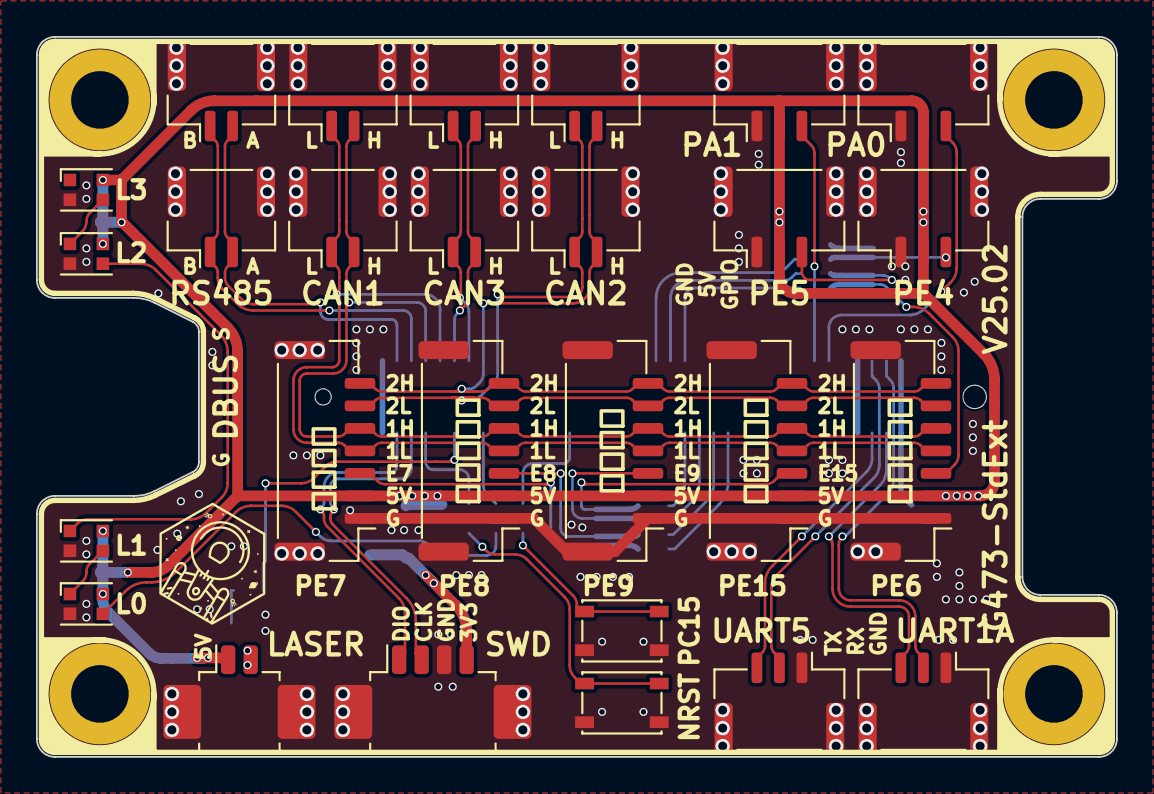
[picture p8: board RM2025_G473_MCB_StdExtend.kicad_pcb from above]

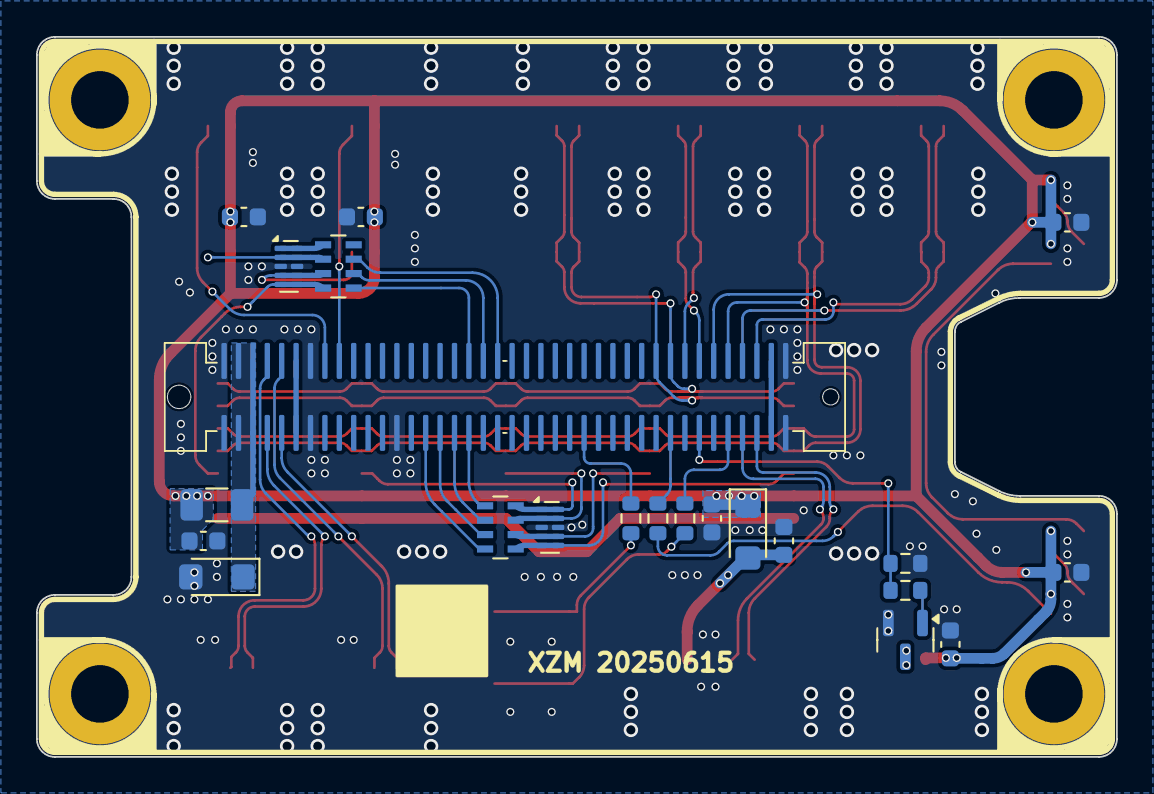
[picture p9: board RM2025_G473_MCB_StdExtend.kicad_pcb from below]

Board: 2 copper layers, 60.0 x 40.0 mm, 53 parts (21 on the bottom side), 49 nets.

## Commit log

2025-08-09 工程文件
    [G473 Core Power.kicad_sch, RM2025_G473_MCB.kicad_pcb, RM2025_G473_MCB.kicad_sch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]
2025-08-09 ibom和加工文件
    [RM2025_G473_MCB.kicad_pcb, RM2025_G473_MCB_StdExtend.kicad_pcb, RM2025_G473_MCB_StdExtend.kicad_sch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]
2025-08-09 更新readme
